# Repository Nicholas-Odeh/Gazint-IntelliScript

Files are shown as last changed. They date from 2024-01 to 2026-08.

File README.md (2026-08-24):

<h1 align="center">Gazint IntelliScript</h1>

IntelliScript is a programmable input device built on an ATmega32U4. The ATmega32U4 provides native USB support, which allows the board to operate as Human Interface Device. Pressing a button on the device executes a preprogrammed sequence of administrative actions onto the workstation the device is connected to. 

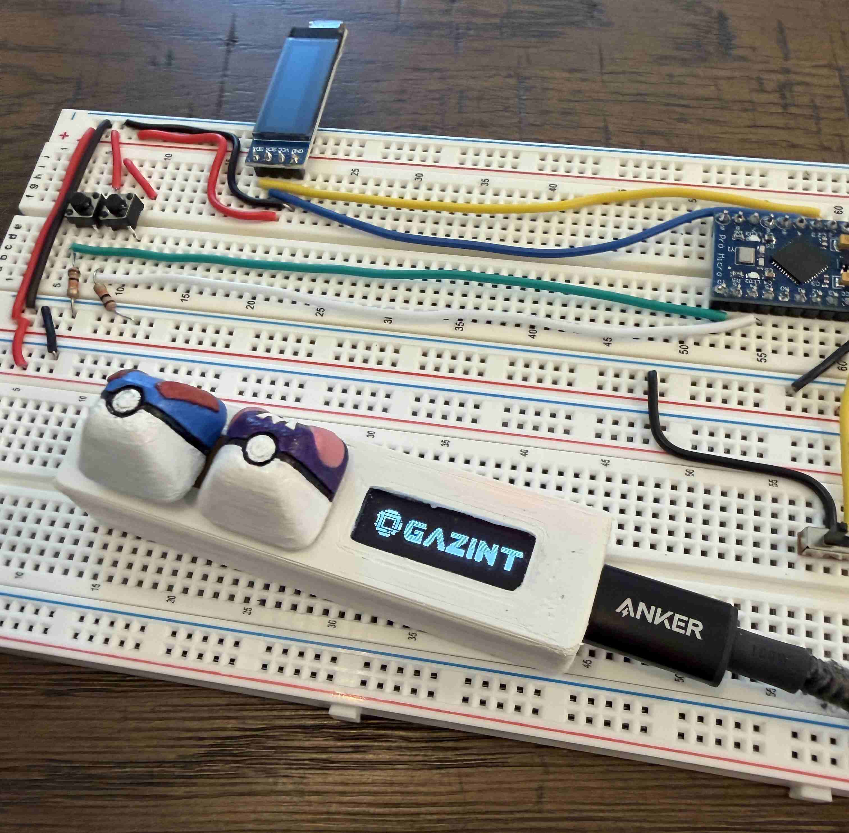
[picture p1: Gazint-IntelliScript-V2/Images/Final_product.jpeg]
IntelliScript reference build


---

<h1 align="center">Repository layout</h1>

| Folder | Contents | Comments |
|---|---|---|
| Code | `Gazint-IntelliScript-V2.ino` | Complete firmware |
| Bitmaps | Bitmap code | Clean line art for 128×32 displays |
| Device-Housing | 3D-printable enclosure | PLA is fine |
| Images | Project images | Breadboard reference and final product |
| SOP | `Gazint-Intelliscript-SOP` | Authorization, handling, risks, and safe practices |

---
<h1 align="center">Hardware</h1>

### Parts

| Part | Notes |
|---|---|
| Arduino Pro Micro (ATmega32U4) | ATmega32U4 is what makes HID emulation possible. |
| 128×32 SSD1306 OLED, I²C | Uses the I²C address `0x3C`. |
| 2 × momentary tactile buttons | Hotkey A and hotkey B. |
| 2 × 10k resistors | One per button, to GND. |
| 2 × LEDs *(optional)* | Development status indicators only; the firmware runs fine without them. |

### Wiring

| Connection | Pro Micro pin |
|---|---|
| OLED SDA | 2 |
| OLED SCL | 3 |
| OLED VCC / GND | VCC / GND |
| Button A | 16 |
| Button B | 15 |
| Red status LED *(optional)* | 5 |
| Green status LED *(optional)* | 6 |

**Buttons are active-HIGH.** So each button connects its pin to VCC when pressed and needs a pull-down
resistor. Without that resistor, the pin floats.

### Breadboard Visual
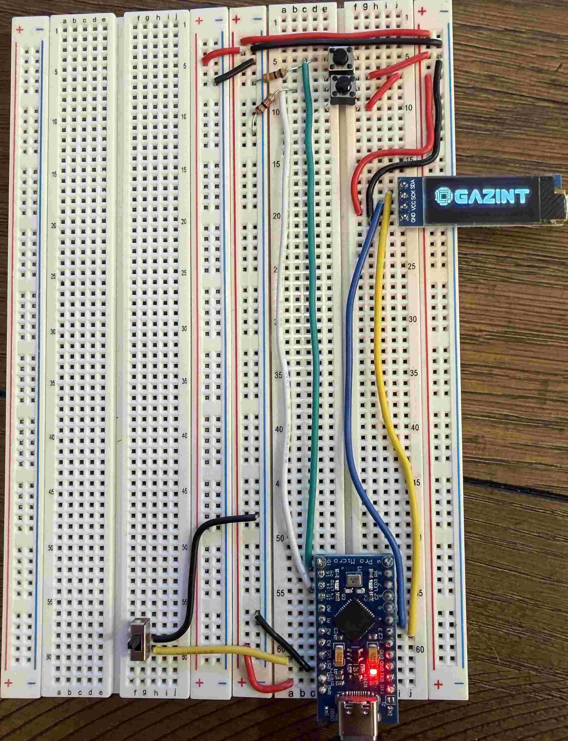
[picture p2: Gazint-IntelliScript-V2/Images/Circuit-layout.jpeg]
IntelliScript reference circuit

---

<h1 align="center">Safety and responsible use</h1>

IntelliScript is a keystroke-injection device. The host cannot tell its input apart from a
person typing on a real keyboard, and that has consequences worth understanding before you build
one.

- **Use it only on systems you own or are authorized to administer.** 
- **It masks keyboard faults.** 
- **A BIOS hotkey embeds your BIOS password in plaintext**
- **Corporate endpoint tooling may flag or block it.** EDR and USB device-control policies
  frequently treat HID injectors as hostile hardware.

`SOP/Gazint-Intelliscript-SOP.pdf` covers all of this in operational detail — authorization,
custody, and change control.

---
<h1 align="center">Demo</h1>

IntelliScript demo

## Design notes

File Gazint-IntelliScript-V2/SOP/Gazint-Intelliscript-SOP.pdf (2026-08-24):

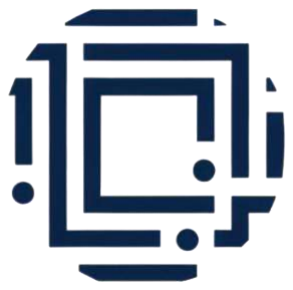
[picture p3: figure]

# Gazint IntelliScript

Standard Operating Procedure

Nicholas Odeh 8/2026

## Contents

## Purpose

Gazint IntelliScript is a hardware IT automation tool that emulates a USB keyboard and mouse to execute administrative input on a workstation. This document outlines the authorization, configuration, operating, and safeguarding requirements for IntelliScript devices.

## What is Gazint IntelliScript?

IntelliScript is a programmable input device built on an ATmega32U4. The ATmega32U4 provides native USB support, which allows the board to operate as Human Interface Device. Pressing a button on the device executes a preprogrammed sequence of administrative actions onto the workstation the device is connected to.

### Device Overview

The following describes IntelliScript’s configuration.

- Controller: ATmega32U4
- HID libraries: HID-Project BootKeyboard and BootMouse
- Inputs: Button A on pin 16 & Button B on pin 15.

### Idle Screen

When the device has power and an administrate action is not being executed, the OLED displays the idle image shown below.

## IntelliScript Usage Requirements

### Authorization

- Connect IntelliScript only to workstations you are already authorized to access and administer.
- Do not connect the device to a workstation belonging to another user, a customer, or a third party without documented approval from Leadership.

### Personnel and Training

- Only personnel trained on this SOP and on the device’s current payloads may operate IntelliScript.

- Know exactly what each button does before connecting the device. Do not press a hotkey to find out what it does.
- Personnel who have not reviewed the documented hotkey behavior within the designated SharePoint file, are not qualified to operate the device.

### Storage and Custody

- Store it in a secure and authorized storage location when not in use.
- Asset tag the device so it is identifiable as IT equipment and not an unknown USB device.

## Using IntelliScript on a Workstation

### Prepare the Workstation

- Confirm you are at the correct workstation and that the work you are about to automate is authorized.
- Save or close unrelated work. IntelliScript input is delivered to whichever window currently has focus.
- If the task requires the BIOS/UEFI screen, bring the workstation to that screen before continuing.

### Connect the Device

- Connect IntelliScript to an available USB port on the target workstation.
- Wait for the OLED to display the idle image, which indicates the device has power and the sketch is running.

### Trigger the Hotkey

- Verify that the intended target is correct.
- Press and release the button for the sequence you intend to run.
- Do not press a second button while a sequence is running.
- Watch the workstation while the sequence executes. If it produces unexpected output, disconnect the device immediately.

### Disconnect and Return

- Disconnect the device once the task is complete. Do not leave it connected to an unattended workstation.
- Verify the workstation is in the expected state before leaving it.
- Return the device to the authorized storage location and record the return in a custody log.

## Risks of Usage

### Native Keyboard Override and Masked Keyboard Failures

IntelliScript supplies keyboard and mouse inputs that the workstation treats exactly as it would input from the built-in or attached keyboard. During hardware troubleshooting this can mask a genuine keyboard failure.

### Stored Credentials in BIOS Hotkeys

A hotkey that unlocks a BIOS/UEFI screen contains the BIOS password as literal text. That value exists in plaintext in the sketch source and in the compiled firmware on the board. Anyone who obtains the device, the source file, or a firmware dump obtains the password. A device programmed this way is a credential, and the exposure extends to every workstation that shares that BIOS password.

### Loss, Theft, or Unattended Devices

The device is small enough to be misplaced and portable enough to be taken. Authorized personnel, secured storage locations and custody logs mitigate this risk.

### Unreviewed Code and Firmware Changes

IntelliScript’s behavior is defined entirely by the code loaded onto the board. Anyone able to connect the board to a computer running the Arduino toolchain can re-flash it, and the OLED image gives no indication that the payload behind a button has changed. An unreviewed edit, an untested change, or a re-flash by an unauthorized party alters what the device does with no visible sign at the point of use.

## Safe Practices

### Verifying Keyboard Function

- When diagnosing a suspected keyboard failure, disconnect IntelliScript before testing.
- Test the workstation’s own keyboard manually and confirm it produces input on its own.
- Do not close or downgrade a keyboard-related ticket on the basis of input delivered through IntelliScript.

### Handling Devices Programmed with a BIOS Password

- Treat a device as a sensitive asset.
- Store it in a secure storage location. Do not leave it in a desk drawer, a bag, or a shared toolkit.
- Do not lend, hand off, or leave the device unattended while it holds a BIOS payload.
- If the device is lost or its custody becomes uncertain, treat the BIOS password as compromised and initiate a password change.

### Physical Custody

- Keep the device either on your person or in authorized storage locations. There is no acceptable state in between.
- Disconnect and store the device before stepping away from a workstation, even briefly.
- Log check-out and returns into the custody log.
- Device must be asset tagged and added to the ServiceNow alm.assets table.
- Report a lost or stolen device to Leadership immediately, and state what payload the device was flashed for.
- Reconcile all IntelliScript devices against the custody log.

### Code and Firmware Change Control

- Only authorized personnel may edit the code or re-flash a device.
- Maintain the sketch in secured sharepoint folder location, with a version identifier.
- Have a two qualified personnel review every payload change before it is flashed.
- Test every change on a non-production workstation before using the device on production or user-facing equipment

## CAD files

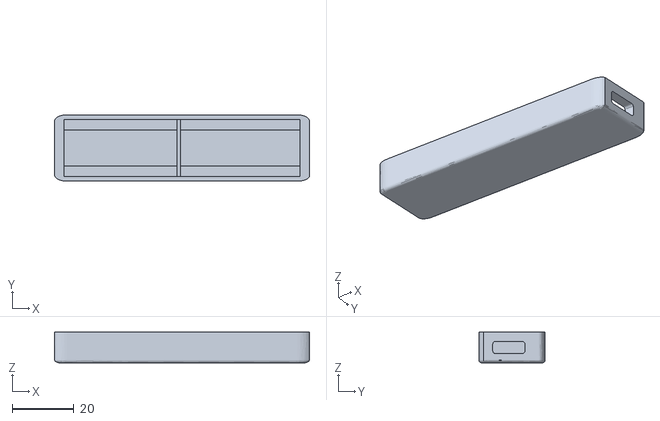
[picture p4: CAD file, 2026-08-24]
Gazint-IntelliScript-V2/Device-Housing/IntelliScript-Case-Bottom.stl
82.5 x 21.5 x 10.00

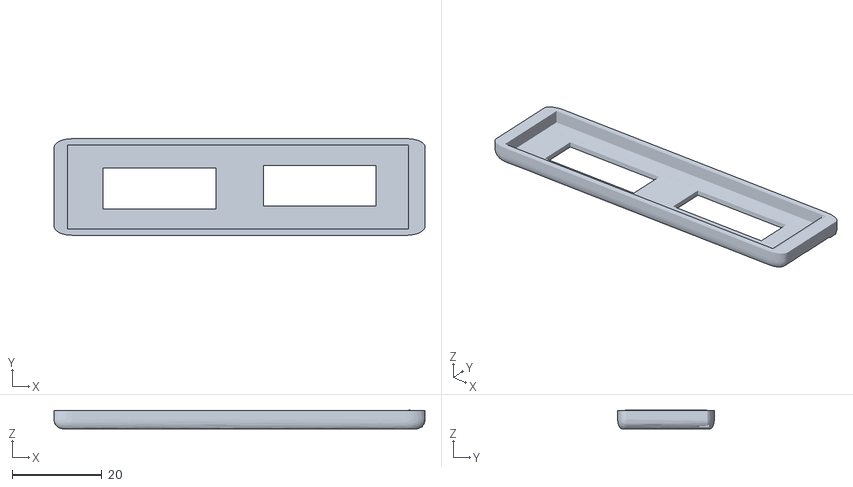
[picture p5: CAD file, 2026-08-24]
Gazint-IntelliScript-V2/Device-Housing/IntelliScript-Case-Top.stl
82.6 x 21.5 x 4.17

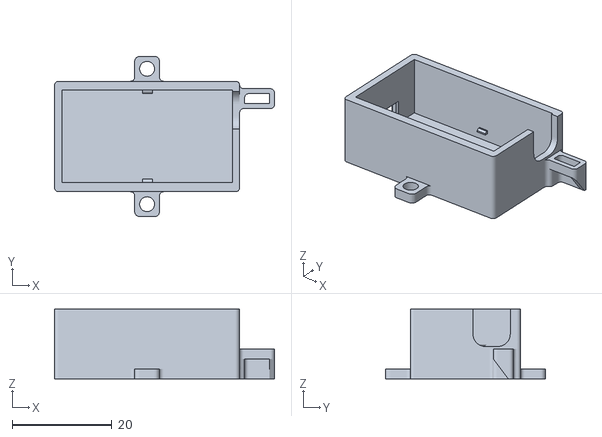
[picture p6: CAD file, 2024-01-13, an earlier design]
Gazint-IntelliScript/generic_housing/arduino_pro_micro_housing.stl
44.2 x 32.2 x 14.0

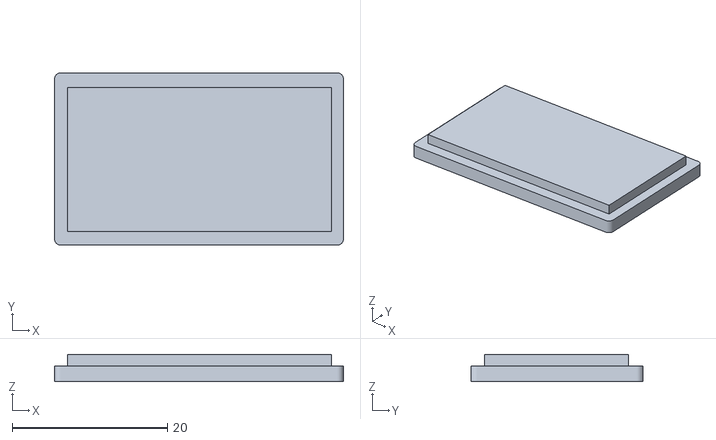
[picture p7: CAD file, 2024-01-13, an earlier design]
Gazint-IntelliScript/generic_housing/arduino_pro_micro_cap.stl
37.2 x 22.2 x 3.50

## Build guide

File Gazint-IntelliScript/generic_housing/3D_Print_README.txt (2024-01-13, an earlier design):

This is a simple arduino pro micro housing created by: kvanderlaag

https://www.thingiverse.com/thing:5767489/files

STL files will be replaced once I finish the final housing design.

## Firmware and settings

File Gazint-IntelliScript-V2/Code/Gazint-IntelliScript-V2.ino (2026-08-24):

//https://github.com/Nicholas-Odeh/Gazint-IntelliScript
//Made by Nicholas Odeh, for IT automation
//CHANGED HID LIBRARY TO UEFI COMPATIBLE LIBRARY
//SEE ADMIN HOTKEY BUTTON TWO FOR DETAILED CODE COMMENTS
//PRO MICRO OLED PINS: 2(SDA) & 3(SCL)


//LIBRARIES USED
#include <Wire.h>
#include <Adafruit_GFX.h>
#include <Adafruit_SSD1306.h>
#include <HID-Project.h>  //UEFI compatible

//PIN ASSIGNMENTS
#define OLED_RESET 4
#define pinA 16 //Button A pin = 16
#define pinB 15 //Button B pin = 15
#define RED_PIN   5 //LED not needed, only for dev purposes 
#define GREEN_PIN 6 //LED not needed, only for dev purposes 
Adafruit_SSD1306 display(OLED_RESET);



//GAZINT TECHNOLOGIES INTELLISCRIPT SLEEP STATE IMAGE
const unsigned char myBitmap1[] PROGMEM = {
	0x00, 0x00, 0x00, 0x00, 0x00, 0x00, 0x00, 0x00, 0x00, 0x00, 0x00, 0x00, 0x00, 0x00, 0x00, 0x00, 
	0x00, 0x00, 0x00, 0x00, 0x00, 0x00, 0x00, 0x00, 0x00, 0x00, 0x00, 0x00, 0x00, 0x00, 0x00, 0x00, 
	0x00, 0x00, 0x00, 0x00, 0x00, 0x00, 0x00, 0x00, 0x00, 0x00, 0x00, 0x00, 0x00, 0x00, 0x00, 0x00, 
	0x00, 0x00, 0x00, 0x00, 0x00, 0x00, 0x00, 0x00, 0x00, 0x00, 0x00, 0x00, 0x00, 0x00, 0x00, 0x00, 
	0x00, 0x00, 0x00, 0x00, 0x00, 0x00, 0x00, 0x00, 0x00, 0x00, 0x00, 0x00, 0x00, 0x00, 0x00, 0x00, 
	0x00, 0x3f, 0xc0, 0x00, 0x00, 0x00, 0x00, 0x00, 0x00, 0x00, 0x00, 0x00, 0x00, 0x00, 0x00, 0x00, 
	0x00, 0xff, 0xd0, 0x00, 0x00, 0x00, 0x00, 0x00, 0x00, 0x00, 0x00, 0x00, 0x00, 0x00, 0x00, 0x00, 
	0x00, 0x00, 0x00, 0x00, 0x00, 0x00, 0x00, 0x00, 0x00, 0x00, 0x00, 0x00, 0x00, 0x00, 0x00, 0x00, 
	0x07, 0x7f, 0xfc, 0x00, 0xff, 0xf0, 0x03, 0x80, 0x3f, 0xff, 0x1e, 0x3c, 0x07, 0x8f, 0xff, 0xf8, 
	0x0f, 0x7f, 0xfc, 0x03, 0xff, 0xf0, 0x07, 0xc0, 0x3f, 0xff, 0x1e, 0x3e, 0x07, 0x8f, 0xff, 0xf8, 
	0x03, 0x00, 0x0c, 0x03, 0xff, 0xf0, 0x07, 0xc0, 0x3f, 0xff, 0x1e, 0x3f, 0x07, 0x8f, 0xff, 0xf8, 
	0x1b, 0x7f, 0xed, 0x03, 0xff, 0xf8, 0x0f, 0xe0, 0x3f, 0xff, 0x1e, 0x3f, 0x87, 0x8f, 0xff, 0xf8, 
	0x0b, 0x40, 0x2c, 0x07, 0xc0, 0x00, 0x0f, 0xe0, 0x00, 0x3e, 0x1e, 0x3f, 0xc7, 0x80, 0x1e, 0x00, 
	0x0b, 0x40, 0x2d, 0x87, 0xc0, 0x00, 0x1f, 0xf0, 0x00, 0x7e, 0x1e, 0x3f, 0xe7, 0x80, 0x1e, 0x00, 
	0x0b, 0x40, 0x2d, 0x87, 0xc0, 0x00, 0x1f, 0xf0, 0x00, 0xfc, 0x1e, 0x3f, 0xf7, 0x80, 0x1e, 0x00, 
	0x0b, 0x40, 0x2d, 0x87, 0xc7, 0xf0, 0x3e, 0xf8, 0x01, 0xf8, 0x1e, 0x3f, 0xf7, 0x80, 0x1e, 0x00, 
	0x0b, 0x40, 0x0d, 0x87, 0xc7, 0xf0, 0x3c, 0xf8, 0x03, 0xf0, 0x1e, 0x3e, 0xff, 0x80, 0x1e, 0x00, 
	0x0b, 0x40, 0x2d, 0x87, 0xc7, 0xf0, 0x7c, 0x78, 0x07, 0xe0, 0x1e, 0x3e, 0xff, 0x80, 0x1e, 0x00, 
	0x03, 0x40, 0x2d, 0x87, 0xc0, 0xf0, 0x7c, 0x7c, 0x0f, 0xc0, 0x1e, 0x3e, 0x7f, 0x80, 0x1e, 0x00, 
	0x1b, 0x40, 0x00, 0x07, 0xc0, 0xf0, 0x78, 0x3c, 0x0f, 0x80, 0x1e, 0x3e, 0x3f, 0x80, 0x1e, 0x00, 
	0x0b, 0x7f, 0xef, 0x07, 0xff, 0xf0, 0xf8, 0x3e, 0x1f, 0xff, 0x1e, 0x3e, 0x1f, 0x80, 0x1e, 0x00, 
	0x03, 0x00, 0x0c, 0x03, 0xff, 0xf0, 0xf0, 0x1e, 0x3f, 0xff, 0x1e, 0x3e, 0x0f, 0x80, 0x1e, 0x00, 
	0x03, 0xfe, 0x5c, 0x03, 0xff, 0xf1, 0xf0, 0x1f, 0x3f, 0xff, 0x1e, 0x3e, 0x07, 0x80, 0x1e, 0x00, 
	0x03, 0xfe, 0xdc, 0x01, 0xff, 0xf1, 0xe0, 0x1f, 0x3f, 0xff, 0x1e, 0x3e, 0x07, 0x80, 0x1e, 0x00, 
	0x00, 0x00, 0x00, 0x00, 0x7f, 0xf1, 0xe0, 0x0f, 0x3f, 0xff, 0x0e, 0x1c, 0x03, 0x80, 0x1e, 0x00, 
	0x00, 0x7f, 0xc0, 0x00, 0x00, 0x00, 0x00, 0x00, 0x00, 0x00, 0x00, 0x00, 0x00, 0x00, 0x00, 0x00, 
	0x00, 0x3f, 0x80, 0x00, 0x00, 0x00, 0x00, 0x00, 0x00, 0x00, 0x00, 0x00, 0x00, 0x00, 0x00, 0x00, 
	0x00, 0x00, 0x00, 0x00, 0x00, 0x00, 0x00, 0x00, 0x00, 0x00, 0x00, 0x00, 0x00, 0x00, 0x00, 0x00, 
	0x00, 0x00, 0x00, 0x00, 0x00, 0x00, 0x00, 0x00, 0x00, 0x00, 0x00, 0x00, 0x00, 0x00, 0x00, 0x00, 
	0x00, 0x00, 0x00, 0x00, 0x00, 0x00, 0x00, 0x00, 0x00, 0x00, 0x00, 0x00, 0x00, 0x00, 0x00, 0x00, 
	0x00, 0x00, 0x00, 0x00, 0x00, 0x00, 0x00, 0x00, 0x00, 0x00, 0x00, 0x00, 0x00, 0x00, 0x00, 0x00, 
	0x00, 0x00, 0x00, 0x00, 0x00, 0x00, 0x00, 0x00, 0x00, 0x00, 0x00, 0x00, 0x00, 0x00, 0x00, 0x00
};

//DEFAULT BITMAP IMAGE
const unsigned char myBitmap2[] PROGMEM = {
  0x55, 0x55, 0x55, 0x55, 0x55, 0x55, 0x55, 0x55, 0x55, 0x55, 0x55, 0x55, 0x55, 0x55, 0x55, 0x55,
  0xaa, 0xaa, 0xaa, 0xaa, 0xaa, 0xaa, 0xaa, 0xaa, 0xa0, 0xa0, 0xaa, 0xaa, 0xaa, 0xaa, 0x0a, 0x0a,
  0x55, 0x55, 0x55, 0x55, 0x55, 0x55, 0x55, 0x55, 0x50, 0x54, 0x55, 0x55, 0x55, 0x55, 0x55, 0x15,
  0xaa, 0xaa, 0xaa, 0xaa, 0xaa, 0xaa, 0xaa, 0xaa, 0xa6, 0x0c, 0xaa, 0xaa, 0xaa, 0xa8, 0xe0, 0x8a,
  0x55, 0x55, 0x55, 0x55, 0x55, 0x55, 0x55, 0x55, 0x47, 0x55, 0x55, 0x55, 0x55, 0x55, 0x75, 0x55,
  0xaa, 0xaa, 0xaa, 0xaa, 0xaa, 0xaa, 0xaa, 0xaa, 0xa7, 0xbe, 0xaa, 0xaa, 0xaa, 0xa8, 0xfb, 0xca,
  0x55, 0x55, 0x55, 0x55, 0x55, 0x55, 0x55, 0x55, 0x55, 0x55, 0x55, 0x55, 0x55, 0x51, 0xd5, 0x55,
  0xaa, 0xaa, 0xaa, 0xaa, 0xaa, 0xaa, 0xaa, 0xaa, 0x8e, 0xfe, 0x2a, 0xaa, 0xaa, 0xa8, 0xff, 0xe2,
  0x55, 0x55, 0x55, 0x55, 0x55, 0x55, 0x55, 0x55, 0x55, 0x55, 0x55, 0x55, 0x55, 0x51, 0x55, 0x55,
  0xaa, 0xaa, 0xaa, 0x2a, 0xa2, 0xaa, 0xaa, 0xaa, 0x8b, 0x8a, 0x2a, 0xaa, 0xaa, 0xa3, 0xb9, 0x82,
  0x55, 0x55, 0x55, 0x05, 0x41, 0x55, 0x55, 0x55, 0x55, 0x54, 0x55, 0x55, 0x55, 0x51, 0x51, 0x45,
  0xaa, 0xaa, 0xaa, 0xb8, 0x1a, 0xaa, 0xaa, 0xaa, 0x8e, 0x8e, 0x2a, 0xaa, 0xaa, 0xaa, 0xf9, 0xe2,
  0x55, 0x55, 0x55, 0x35, 0x51, 0x55, 0x55, 0x55, 0x55, 0x5d, 0x55, 0x55, 0x55, 0x51, 0x55, 0x35,
  0xaa, 0xaa, 0x80, 0x3f, 0xba, 0xaa, 0xaa, 0xaa, 0x83, 0xbb, 0x2a, 0xaa, 0xaa, 0x02, 0xbb, 0xa2,
  0x55, 0x55, 0x54, 0x75, 0x51, 0x55, 0x55, 0x55, 0x55, 0xfc, 0x55, 0x55, 0x55, 0x51, 0x5f, 0xd5,
  0xaa, 0xaa, 0x3e, 0x3e, 0xea, 0xaa, 0xaa, 0xa8, 0x07, 0xf8, 0xaa, 0xaa, 0xaa, 0xe8, 0x7f, 0x8a,
  0x55, 0x55, 0x55, 0x55, 0x55, 0x55, 0x55, 0x51, 0x55, 0xf5, 0x55, 0x15, 0x55, 0x55, 0x5f, 0x15,
  0xaa, 0xa8, 0xba, 0x3b, 0x38, 0xaa, 0xaa, 0xa3, 0xbb, 0xf2, 0xaa, 0x2a, 0xa3, 0xba, 0xbe, 0x2a,
  0x55, 0x55, 0x55, 0x55, 0x51, 0x55, 0x55, 0x45, 0x55, 0xf5, 0x54, 0x55, 0x55, 0x55, 0x5f, 0x55,
  0xaa, 0xaa, 0xfe, 0x3f, 0xf8, 0xaa, 0xaa, 0x8f, 0xeb, 0xf2, 0xaa, 0x22, 0xa3, 0xfe, 0xbe, 0x2a,
  0x55, 0x51, 0x55, 0x55, 0x75, 0x55, 0x55, 0x55, 0x55, 0xf5, 0x55, 0x15, 0x45, 0x55, 0x7f, 0x55,
  0xaa, 0xa3, 0xba, 0x3f, 0xfa, 0xaa, 0xaa, 0x0b, 0xbb, 0xe2, 0xaa, 0x1a, 0x8b, 0xab, 0xbe, 0x2a,
  0x55, 0x55, 0x55, 0x5f, 0xf5, 0x55, 0x55, 0x15, 0x55, 0xd5, 0x55, 0x55, 0x55, 0x75, 0x7d, 0x55,
  0xaa, 0xa2, 0xef, 0x8f, 0xe2, 0xaa, 0xaa, 0x0f, 0xbf, 0xa2, 0xaa, 0x88, 0x8f, 0xfa, 0xf8, 0xaa,
  0x55, 0x55, 0x75, 0x57, 0xd5, 0x55, 0x55, 0x15, 0x17, 0xd5, 0x55, 0x55, 0x55, 0x71, 0x75, 0x55,
  0x80, 0x03, 0xe9, 0xaf, 0xea, 0xaa, 0x00, 0x0b, 0x9b, 0x22, 0xaa, 0x8a, 0x03, 0xe1, 0x80, 0xaa,
  0x55, 0x45, 0xc5, 0x51, 0x15, 0x55, 0x55, 0x17, 0x15, 0x55, 0x55, 0x55, 0x55, 0x71, 0x55, 0x55,
  0x8a, 0x82, 0xe0, 0xfc, 0xca, 0xaa, 0x2a, 0x0e, 0xc6, 0x62, 0xaa, 0xa2, 0x81, 0xcc, 0xee, 0xaa,
  0x51, 0x01, 0x51, 0x55, 0x55, 0x55, 0x11, 0x15, 0x45, 0x55, 0x55, 0x51, 0x01, 0x54, 0x55, 0x55,
  0x00, 0x00, 0x00, 0x00, 0x02, 0xa8, 0x00, 0x00, 0x00, 0x00, 0xa8, 0x80, 0x00, 0x00, 0x00, 0x2a,
  0x55, 0x55, 0x55, 0x55, 0x55, 0x55, 0x55, 0x55, 0x55, 0x55, 0x55, 0x55, 0x55, 0x55, 0x55, 0x55,
  0xaa, 0xaa, 0xaa, 0xaa, 0xaa, 0xaa, 0xaa, 0xaa, 0xaa, 0xaa, 0xaa, 0xaa, 0xaa, 0xaa, 0xaa, 0xaa
};

//EMPTY BITMAP
const unsigned char myBitmap3[] PROGMEM = {
};


void setup() {

  pinMode(pinA, INPUT);  // Button A (Pin 16)
  pinMode(pinB, INPUT);  // Button B (Pin 15)
  display.begin(SSD1306_SWITCHCAPVCC, 0x3C);  //I2C address
  display.clearDisplay();
  BootKeyboard.begin();
  BootMouse.begin();
}

void loop() {
  display.display();
  display.drawBitmap(0, 0, myBitmap1, 128, 32, WHITE); 
  display.display();
  delay(200);

//Admin Hotkey Button One 
  if (digitalRead(pinA) == HIGH) { //pinA = pin 16
    Serial.println("Button A pressed"); 
    display.clearDisplay();
    display.drawBitmap(0, 0, myBitmap2, 128, 32, WHITE); 
    display.display();
    delay(50);
    BootMouse.click(MOUSE_LEFT);
    display.display();
    delay(50);
    BootKeyboard.print("Button A pressed");
    delay(100);
    BootKeyboard.write(KEY_RETURN);
    delay(50);
    while (digitalRead(pinA) == HIGH);
    delay(150);
    display.clearDisplay();

  }

// Admin Hotkey Button Two 
if (digitalRead(pinB) == HIGH) { // pinB = pin 15
  Serial.println("Button B pressed"); //Serial monitor
  display.clearDisplay(); //Display refresh cycle
  display.drawBitmap(0, 0, myBitmap2, 128, 32, WHITE); //Bitmap selection 
  display.display();
  delay(50); //Delay timeframe in ms
  BootMouse.click(MOUSE_LEFT); //Left Click
  delay(50);
  BootKeyboard.print("Button B pressed"); //HID output
  delay(150);
  BootKeyboard.write(KEY_RETURN); //Enter button
  delay(50);
  BootKeyboard.write(KEY_DOWN_ARROW); //Down arrow key
  delay(50);
  BootMouse.move(-100, 0); //Move left 
  delay(50);
  BootMouse.move(100, 0); //Move right
  delay(50);
  BootMouse.move(0, -100); //Move up
  delay(50);
  BootMouse.move(0, 100); //Move down
  delay(50);
  while (digitalRead(pinB) == HIGH);
  delay(150); // Wait for button release
  display.clearDisplay();
}


}

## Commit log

2024-01-13 IntelliScript 1.0
    [arduino_pro_micro_cap.stl, arduino_pro_micro_housing.stl]
2026-07-29 Add files via upload
    V3 of the code: physical verification needed. ETA of physical verication EOY 2026. Prototype/experiment with Claude Sonnet 5, using Ultracode Intelligence level. Prompt input and outputs have been ad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
2026-08-24 IntelliScript 2.0
    [IntelliScript-Case-Bottom.stl, IntelliScript-Case-Top.stl]
